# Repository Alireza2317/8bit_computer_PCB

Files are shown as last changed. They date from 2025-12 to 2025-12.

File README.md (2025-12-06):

# PCB Design of Ben Eater's 8-Bit Computer 🖥️





A complete **Printed Circuit Board (PCB)** implementation of the famous 8-bit computer architecture (SAP-1) designed by Ben Eater.

Moving from breadboards to a production-ready PCB, this project demonstrates complex signal routing, hierarchical schematic organization, and digital logic design using the **74xx TTL series** chips.

## 📸 3D Render
<p align="center">
  3D Top View
</p>

## ⚙️ Technical Specifications
| Feature | Details |
| :--- | :--- |
| **EDA Software** | KiCad |
| **Architecture** | Simple As Possible |
| **Logic Family** | 74LS / 74HC Series (TTL) |
| **PCB Layers** | 2 Layers |
| **Mounting** | Through-Hole Technology (THT) |

## 🧠 Design Challenges & Features
* **Hierarchical Schematics:** The design is broken down into modular logical blocks (Clock, RAM, ALU, Control Logic) using KiCad's hierarchical sheets for maintainability.
* **Complex Routing:** Managing hundreds of data and control lines on a 2-layer board required careful optimization of trace paths to minimize vias and ensure signal integrity.
* **Bus Architecture:** Implements a central 8-bit bus connecting all registers and the Arithmetic Logic Unit.

## 🖼️ Gallery

#### PCB Layout
<p align="center">
  PCB Layout
</p>

#### 3d View Snapshot
<p align="center">
  3D Top View
</p>

### Schematics (Sneak Peek)

#### Root schematic page
<p align="center">
  root schematics
</p>

#### RAM Module
<p align="center">
	Memory schematics
</p>

## 🚀 How to Open
1. **Clone the repository:**
   ```bash
   git clone https://github.com/Alireza2317/8bit_computer_PCB
   ```
2. **Open in KiCad:**
   * Launch **KiCad**.
   * Go to `File > Open Project`.
   * Select the `.kicad_pro` file in the root directory.
3. **Explore:**
   * Click the **Schematic Editor** to see the logic.
   * Click the **PCB Editor** to see the physical routing.

## 👏 Acknowledgments
This project is based on the incredible educational series by **Ben Eater**.
* [Ben Eater's Website](https://eater.net/8bit)
* [YouTube Playlist](https://www.youtube.com/playlist?list=PLowKtXNTBypGqImE405J2565dvjafglHU)

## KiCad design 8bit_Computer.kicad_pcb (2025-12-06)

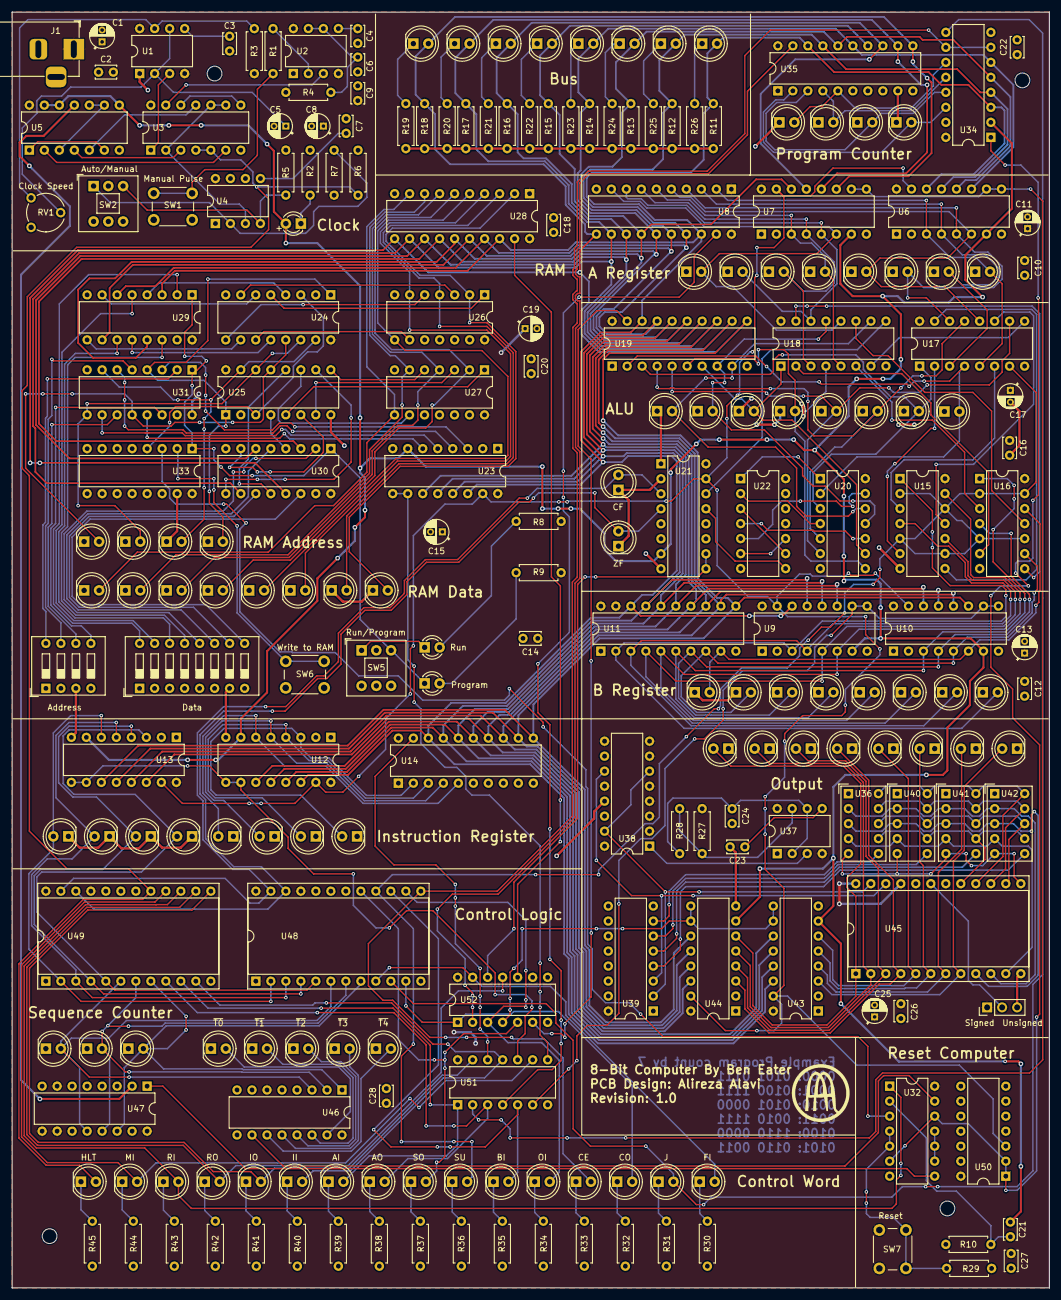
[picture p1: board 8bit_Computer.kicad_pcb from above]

Board: 2 copper layers, 175.6 x 216.0 mm, 232 parts (0 on the bottom side), 231 nets.

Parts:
C1, C5: 100nF; CP_Radial_D4.0mm_P2.00mm
C2, C9, C14, C16, C18, C21: 1uF; C_Disc_D3.4mm_W2.1mm_P2.50mm
C3, C4, C7, C10, C12, C20, C22, C23, C24, C26, C27, C28: 10nF; C_Disc_D3.4mm_W2.1mm_P2.50mm
C6: 100nF; C_Disc_D3.4mm_W2.1mm_P2.50mm
C8: 2.2uF; CP_Radial_D4.0mm_P2.00mm
C11, C15, C17, C19: 10nF; CP_Radial_D4.0mm_P2.00mm
C13, C25: 1uF; CP_Radial_D4.0mm_P2.00mm
D1: bus7; LED_D3.0mm
D2: bus6; LED_D5.0mm
D3: bus5; LED_D5.0mm
D4: bus4; LED_D5.0mm
D5: bus3; LED_D5.0mm
D6: bus2; LED_D5.0mm
D7: bus1; LED_D5.0mm
D8: bus0; LED_D5.0mm
D9: pc3; LED_D5.0mm
D10: pc2; LED_D5.0mm
D11: pc1; LED_D5.0mm
D12: pc0; LED_D5.0mm
D13: Clock LED; LED_D5.0mm
D14: a7; LED_D5.0mm
D15: a6; LED_D5.0mm
D16: a5; LED_D5.0mm
D17: a4; LED_D5.0mm
D18: a3; LED_D5.0mm
D19: a2; LED_D5.0mm
D20: a0; LED_D5.0mm
D21: a1; LED_D5.0mm
D22: s7; LED_D5.0mm
D23: s5; LED_D5.0mm
D24: s6; LED_D5.0mm
D25: s4; LED_D5.0mm
D26: s3; LED_D5.0mm
D27: s2; LED_D5.0mm
D28: s1; LED_D5.0mm
D29: s0; LED_D5.0mm
D30: CF; LED_D5.0mm
D31: ra3; LED_D5.0mm
D32: ra2; LED_D5.0mm
D33: ra0; LED_D5.0mm
D34: ra1; LED_D5.0mm
D35: ZF; LED_D5.0mm
D36: r7; LED_D5.0mm
D37: r6; LED_D5.0mm
D38: r4; LED_D5.0mm
D39: r5; LED_D5.0mm
D40: r3; LED_D5.0mm
D41: r2; LED_D5.0mm
D42: r0; LED_D5.0mm
D43: r1; LED_D5.0mm
D44: Run; LED_D5.0mm
D45: Program; LED_D5.0mm
D46: b6; LED_D5.0mm
D47: b7; LED_D5.0mm
D48: b5; LED_D3.0mm
D49: b4; LED_D3.0mm
D50: b2; LED_D5.0mm
D51: b3; LED_D5.0mm
D52: b0; LED_D5.0mm
D53: b1; LED_D5.0mm
D54: out7; LED_D5.0mm
D55: out6; LED_D5.0mm
D56: out5; LED_D5.0mm
D57: out3; LED_D5.0mm
D58: out4; LED_D5.0mm
D59: out2; LED_D5.0mm
D60: out1; LED_D5.0mm
D61: out0; LED_D5.0mm
D62: ir7; LED_D5.0mm
D63: ir6; LED_D5.0mm
D64: ir5; LED_D5.0mm
D65: ir3; LED_D5.0mm
D66: ir4; LED_D5.0mm
D67: ir2; LED_D5.0mm
D68: ir1; LED_D5.0mm
D69: ir0; LED_D5.0mm
D70: sc1; LED_D5.0mm
D71: sc2; LED_D5.0mm
D72: sc0; LED_D5.0mm
D73: T0; LED_D5.0mm
D74: T2; LED_D5.0mm
D75: T1; LED_D5.0mm
D76: T4; LED_D5.0mm
D77: T3; LED_D5.0mm
D78: HLT; LED_D5.0mm
D79: MAR_In; LED_D5.0mm
D80: RAM_In; LED_D5.0mm
D81: RAM_Out; LED_D5.0mm
D82: IR_Out; LED_D5.0mm
D83: IR_In; LED_D5.0mm
D84: A_Out; LED_D5.0mm
D85: A_In; LED_D5.0mm
D86: Sum_Out; LED_D5.0mm
D87: Subtract; LED_D5.0mm
D88: Out_In; LED_D5.0mm
D89: B_In; LED_D5.0mm
D90: PC_En; LED_D5.0mm
D91: PC_Out; LED_D5.0mm
D92: Jump; LED_D5.0mm
D93: Flags_In; LED_D5.0mm
J1: DC Input; BarrelJack_Horizontal
J2: Sign Mode Jumper; PinHeader_1x03_P2.54mm_Vertical
M1, M2, M3, M4: MountingHole_2.5mm
R1, R3, R20, R22, R27: 1K; R_Axial_DIN0207_L6.3mm_D2.5mm_P7.62mm_Horizontal
R2: 1M; R_Axial_DIN0207_L6.3mm_D2.5mm_P7.62mm_Horizontal
R4, R5, R7, R9, R11, R13, R16, R19: 100; R_Axial_DIN0207_L6.3mm_D2.5mm_P7.62mm_Horizontal
R6, R8, R10, R12, R14, R15, R17, R18, R23, R44: 10K; R_Axial_DIN0207_L6.3mm_D2.5mm_P7.62mm_Horizontal
R21, R24, R25, R28, R29, R30, R31, R32, R33, R34, R35, R36, R37, R38, R39, R40, R41, R42, R43: 330; R_Axial_DIN0207_L6.3mm_D2.5mm_P7.62mm_Horizontal
R26: 100K; R_Axial_DIN0207_L6.3mm_D2.5mm_P7.62mm_Horizontal
R45: 1k; R_Axial_DIN0207_L6.3mm_D2.5mm_P7.62mm_Horizontal
RV1: 100K; Potentiometer_Piher_PT-6-V_Vertical
SW1: Clock Mode Switch; SW_PUSH_6mm
SW2: Manual Pulse; SW_Push_2P2T_Toggle_CK_PVA2OAH5xxxxxxV2
SW3: Program Address; SW_DIP_SPSTx04_Slide_9.78x12.34mm_W7.62mm_P2.54mm
SW4: Program Data; SW_DIP_SPSTx08_Slide_9.78x22.5mm_W7.62mm_P2.54mm
SW5: Program Button; SW_Push_2P2T_Toggle_CK_PVA2OAH5xxxxxxV2
SW6: Program/Run Mode Switch; SW_PUSH_6mm
SW7: Reset Button; SW_PUSH_6mm
U1, U2: NE555P; DIP-8_W7.62mm
U3: 74LS245; DIP-14_W7.62mm
U4: 74LS00; DIP-8_W7.62mm
U5, U50, U52: 74LS00; DIP-14_W7.62mm
U6, U9, U18, U29, U34: 74LS245; DIP-16_W7.62mm
U7, U47: 74LS161; DIP-16_W7.62mm
U8: NE555P; DIP-20_W7.62mm
U10, U23, U24, U30, U31, U33, U44: 74LS173; DIP-16_W7.62mm
U11: 74LS173; DIP-20_W7.62mm
U12, U21: 74LS157; DIP-16_W7.62mm
U13: 74LS189; DIP-16_W7.62mm
U14: 74LS04; DIP-20_W7.62mm
U15: 74LS189; DIP-14_W7.62mm
U16, U22: 74LS157; DIP-14_W7.62mm
U17: 74LS04; DIP-16_W7.62mm
U19: 74LS283; DIP-20_W7.62mm
U20: 74LS283; DIP-14_W7.62mm
U25: 74LS08; DIP-16_W7.62mm
U26: 74LS02; DIP-14_W7.62mm
U27: 74LS86; DIP-14_W7.62mm
U28: 74LS86; DIP-20_W7.62mm
U32: 74LS173; DIP-14_W7.62mm
U35: 74LS76; DIP-20_W7.62mm
U36: NE555D; HDSP-7401
U37: Hundred's Place; DIP-8_W7.62mm
U38: Minus Sign; DIP-16_W7.62mm
U39: Ten's Place; DIP-16_W7.62mm
U40: One's Place; HDSP-7401
U41, U42: 28c16; HDSP-7401
U43: 74LS139; DIP-16_W7.62mm
U45: 74LS173; DIP-24_W15.24mm_Socket
U46: 28c16; DIP-16_W7.62mm
U48: 74LS138; DIP-24_W15.24mm_Socket
U49: 74LS06; DIP-24_W15.24mm_Socket
U51: 74LS06; DIP-14_W7.62mm

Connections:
/A Register/a0: D9.2 (A), U6.3 (Q0), U8.2 (A0), U17.5 (A1)
/A Register/a1: D8.2 (A), U6.4 (Q1), U8.3 (A1), U17.3 (A2)
/A Register/a2: D7.2 (A), U6.5 (Q2), U8.4 (A2), U17.14 (A3)
/A Register/a3: D6.2 (A), U6.6 (Q3), U8.5 (A3), U17.12 (A4)
/A Register/a4: D5.2 (A), U7.3 (Q0), U8.6 (A4), U18.5 (A1)
/A Register/a5: D4.2 (A), U7.4 (Q1), U8.7 (A5), U18.3 (A2)
/A Register/a6: D3.2 (A), U7.5 (Q2), U8.8 (A6), U18.14 (A3)
/A Register/a7: D2.2 (A), U7.6 (Q3), U8.9 (A7), U18.12 (A4)
/ALU/Flags Register/zero_bit: U21.13 (D1), U22.8
/ALU/bc0: U15.3, U17.6 (B1)
/ALU/bc1: U15.6, U17.2 (B2)
/ALU/bc2: U15.8, U17.15 (B3)
/ALU/bc3: U15.11, U17.11 (B4)
/ALU/bc4: U16.3, U18.6 (B1)
/ALU/bc5: U16.6, U18.2 (B2)
/ALU/bc6: U16.8, U18.15 (B3)
/ALU/bc7: U16.11, U18.11 (B4)
/ALU/carry_bit: U18.9 (C4), U21.14 (D0)
/ALU/middle_carry: U17.9 (C4), U18.7 (C0)
/ALU/s0: D33.2 (A), U17.4 (S1), U19.2 (A0), U20.2
/ALU/s1: D32.2 (A), U17.1 (S2), U19.3 (A1), U20.3
/ALU/s2: D31.2 (A), U17.13 (S3), U19.4 (A2), U20.5
/ALU/s3: D30.2 (A), U17.10 (S4), U19.5 (A3), U20.6
/ALU/s4: D29.2 (A), U18.4 (S1), U19.6 (A4), U20.8
/ALU/s5: D28.2 (A), U18.1 (S2), U19.7 (A5), U20.9
/ALU/s6: D27.2 (A), U18.13 (S3), U19.8 (A6), U20.11
/ALU/s7: D26.2 (A), U18.10 (S4), U19.9 (A7), U20.12
/B Register/b0: D17.2 (A), U9.3 (Q0), U11.2 (A0), U15.1
/B Register/b1: D16.2 (A), U9.4 (Q1), U11.3 (A1), U15.4
/B Register/b2: D15.2 (A), U9.5 (Q2), U11.4 (A2), U15.10
/B Register/b3: D14.2 (A), U9.6 (Q3), U11.5 (A3), U15.13
/B Register/b4: D13.2 (A), U10.3 (Q0), U11.6 (A4), U16.1
/B Register/b5: D12.2 (A), U10.4 (Q1), U11.7 (A5), U16.4
/B Register/b6: D11.2 (A), U10.5 (Q2), U11.8 (A6), U16.9
/B Register/b7: D10.2 (A), U10.6 (Q3), U11.9 (A7), U16.12
/Clock Module/AO: U1.3 (Q), U3.1
/Clock Module/MO: U2.3 (Q), U3.13
/Clock Module/select clock mode: U3.2, U3.9, U3.10, U4.3 (Q)
/Control Logic/sc0: D75.2 (A), U46.1 (A0), U47.14 (Q0), U48.8 (A0), U49.8 (A0)
/Control Logic/sc1: D73.2 (A), U46.2 (A1), U47.13 (Q1), U48.7 (A1), U49.7 (A1)
/Control Logic/sc2: D71.2 (A), U46.3 (A2), U47.12 (Q2), U48.6 (A2), U49.6 (A2)
/Control Logic/~T0: D70.2 (A), U46.15 (O0)
/Control Logic/~T1: D72.2 (A), U46.14 (O1)
/Control Logic/~T2: D74.2 (A), U46.13 (O2)
/Control Logic/~T3: D76.2 (A), U46.12 (O3)
/Control Logic/~T4: D77.2 (A), U46.11 (O4)
/Control Logic/~T5: U32.13, U46.10 (O5)
/Control Logic/~sq_mr: U32.8, U47.1 (~MR)
/Display/a: U36.10 (A), U40.10 (A), U41.10 (A), U42.10 (A), U45.16 (I/O6)
/Display/b: U36.9 (B), U40.9 (B), U41.9 (B), U42.9 (B), U45.15 (I/O5)
/Display/c: U36.8 (C), U40.8 (C), U41.8 (C), U42.8 (C), U45.14 (I/O4)
/Display/d: U36.5 (D), U40.5 (D), U41.5 (D), U42.5 (D), U45.13 (I/O3)
/Display/dp: U36.7 (DP), U40.7 (DP), U41.7 (DP), U42.7 (DP), U45.17 (I/O7)
/Display/e: U36.4 (E), U40.4 (E), U41.4 (E), U42.4 (E), U45.11 (I/O2)
/Display/f: U36.2 (F), U40.2 (F), U41.2 (F), U42.2 (F), U45.10 (I/O1)
/Display/g: U36.3 (G), U40.3 (G), U41.3 (G), U42.3 (G), U45.9 (I/O0)
/Display/hundreds: U39.6 (O2), U40.6 (CC)
/Display/mc0: U38.6 (C), U38.15 (Q), U39.2 (A0), U45.23 (A8)
/Display/mc1: U38.11 (Q), U39.3 (A1), U45.22 (A9)
/Display/mux_clock: U37.3 (Q), U38.1 (C)
/Display/ones: U39.4 (O0), U42.6 (CC)
/Display/out0: D69.2 (A), U43.3 (Q0), U45.8 (A0)
/Display/out1: D68.2 (A), U43.4 (Q1), U45.7 (A1)
/Display/out2: D67.2 (A), U43.5 (Q2), U45.6 (A2)
/Display/out3: D66.2 (A), U43.6 (Q3), U45.5 (A3)
/Display/out4: D65.2 (A), U44.3 (Q0), U45.4 (A4)
/Display/out5: D64.2 (A), U44.4 (Q1), U45.3 (A5)
/Display/out6: D63.2 (A), U44.5 (Q2), U45.2 (A6)
/Display/out7: D62.2 (A), U44.6 (Q3), U45.1 (A7)
/Display/sign: U36.6 (CC), U39.7 (O3)
/Display/tens: U39.5 (O1), U41.6 (CC)
/Instruction Register/ir0: D25.2 (A), U12.3 (Q0), U14.2 (A0)
/Instruction Register/ir1: D24.2 (A), U12.4 (Q1), U14.3 (A1)
/Instruction Register/ir2: D23.2 (A), U12.5 (Q2), U14.4 (A2)
/Instruction Register/ir3: D22.2 (A), U12.6 (Q3), U14.5 (A3)
/Instruction Register/ir4: D21.2 (A), U13.3 (Q0), U48.5 (A3), U49.5 (A3)
/Instruction Register/ir5: D20.2 (A), U13.4 (Q1), U48.4 (A4), U49.4 (A4)
/Instruction Register/ir6: D19.2 (A), U13.5 (Q2), U48.3 (A5), U49.3 (A5)
/Instruction Register/ir7: D18.2 (A), U13.6 (Q3), U48.2 (A6), U49.2 (A6)
/Program Counter/pc0: D53.2 (A), U34.14 (Q0), U35.2 (A0)
/Program Counter/pc1: D52.2 (A), U34.13 (Q1), U35.3 (A1)
/Program Counter/pc2: D51.2 (A), U34.12 (Q2), U35.4 (A2)
/Program Counter/pc3: D50.2 (A), U34.11 (Q3), U35.5 (A3)
/RAM/Computer Mode Switcher/di0: U24.4 (D1), U29.4 (Za)
/RAM/Computer Mode Switcher/di1: U24.6 (D2), U29.7 (Zb)
/RAM/Computer Mode Switcher/di2: U24.10 (D3), U29.9 (Zc)
/RAM/Computer Mode Switcher/di3: U24.12 (D4), U29.12 (Zd)
/RAM/Computer Mode Switcher/di4: U25.4 (D1), U30.4 (Za)
/RAM/Computer Mode Switcher/di5: U25.6 (D2), U30.7 (Zb)
/RAM/Computer Mode Switcher/di6: U25.10 (D3), U30.9 (Zc)
/RAM/Computer Mode Switcher/di7: U25.12 (D4), U30.12 (Zd)
/RAM/Computer Mode Switcher/mar0: U23.3 (Q0), U31.3 (I1a)
/RAM/Computer Mode Switcher/mar1: U23.4 (Q1), U31.6 (I1b)
/RAM/Computer Mode Switcher/mar2: U23.5 (Q2), U31.10 (I1c)
/RAM/Computer Mode Switcher/mar3: U23.6 (Q3), U31.13 (I1d)
/RAM/Computer Mode Switcher/pa0: SW3.8, U31.2 (I0a)
/RAM/Computer Mode Switcher/pa1: SW3.7, U31.5 (I0b)
/RAM/Computer Mode Switcher/pa2: SW3.6, U31.11 (I0c)
/RAM/Computer Mode Switcher/pa3: SW3.5, U31.14 (I0d)
/RAM/Computer Mode Switcher/pd0: SW4.16, U29.2 (I0a)
/RAM/Computer Mode Switcher/pd1: SW4.15, U29.5 (I0b)
/RAM/Computer Mode Switcher/pd2: SW4.14, U29.11 (I0c)
/RAM/Computer Mode Switcher/pd3: SW4.13, U29.14 (I0d)
/RAM/Computer Mode Switcher/pd4: SW4.12, U30.2 (I0a)
/RAM/Computer Mode Switcher/pd5: SW4.11, U30.5 (I0b)
/RAM/Computer Mode Switcher/pd6: SW4.10, U30.11 (I0c)
/RAM/Computer Mode Switcher/pd7: SW4.9, U30.14 (I0d)
/RAM/Computer Mode Switcher/select r/p: D49.1 (K), SW5.3 (C), U29.1 (S), U30.1 (S), U31.1 (S), U33.1 (S)
/RAM/Computer Mode Switcher/~RAM_WE: U24.3 (~WE), U25.3 (~WE), U33.4 (Za)
/RAM/a0: D39.2 (A), U24.1 (A0), U25.1 (A0), U31.4 (Za)
/RAM/a1: D38.2 (A), U24.15 (A1), U25.15 (A1), U31.7 (Zb)
/RAM/a2: D37.2 (A), U24.14 (A2), U25.14 (A2), U31.9 (Zc)
/RAM/a3: D36.2 (A), U24.13 (A3), U25.13 (A3), U31.12 (Zd)
/RAM/r0: D47.2 (A), U26.2, U28.2 (A0)
/RAM/r1: D46.2 (A), U26.4, U28.3 (A1)
/RAM/r2: D45.2 (A), U26.6, U28.4 (A2)
/RAM/r3: D44.2 (A), U26.8, U28.5 (A3)
/RAM/r4: D43.2 (A), U27.2, U28.6 (A4)
/RAM/r5: D42.2 (A), U27.4, U28.7 (A5)
/RAM/r6: D41.2 (A), U27.6, U28.8 (A6)
/RAM/r7: D40.2 (A), U27.8, U28.9 (A7)
A_In: D87.2 (A), U49.10 (I/O1), U51.1
A_Out: D86.2 (A), U49.9 (I/O0), U51.3
B_In: D83.2 (A), U48.15 (I/O5), U51.5
Bus0: D61.2 (A), R11.1, U6.14 (D0), U8.18 (B0), U9.14 (D0), U11.18 (B0), U12.14 (D0), U14.18 (B0), U19.18 (B0), U23.14 (D0), U28.18 (B0), U29.3 (I1a), U34.3 (D0), U35.18 (B0), U43.14 (D0)
Bus1: D60.2 (A), R12.1, U6.13 (D1), U8.17 (B1), U9.13 (D1), U11.17 (B1), U12.13 (D1), U14.17 (B1), U19.17 (B1), U23.13 (D1), U28.17 (B1), U29.6 (I1b), U34.4 (D1), U35.17 (B1), U43.13 (D1)
Bus2: D59.2 (A), R13.1, U6.12 (D2), U8.16 (B2), U9.12 (D2), U11.16 (B2), U12.12 (D2), U14.16 (B2), U19.16 (B2), U23.12 (D2), U28.16 (B2), U29.10 (I1c), U34.5 (D2), U35.16 (B2), U43.12 (D2)
Bus3: D58.2 (A), R14.1, U6.11 (D3), U8.15 (B3), U9.11 (D3), U11.15 (B3), U12.11 (D3), U14.15 (B3), U19.15 (B3), U23.11 (D3), U28.15 (B3), U29.13 (I1d), U34.6 (D3), U35.15 (B3), U43.11 (D3)
Bus4: D57.2 (A), R15.1, U7.14 (D0), U8.14 (B4), U10.14 (D0), U11.14 (B4), U13.14 (D0), U14.14 (B4), U19.14 (B4), U28.14 (B4), U30.3 (I1a), U35.14 (B4), U44.14 (D0)
Bus5: D56.2 (A), R16.1, U7.13 (D1), U8.13 (B5), U10.13 (D1), U11.13 (B5), U13.13 (D1), U14.13 (B5), U19.13 (B5), U28.13 (B5), U30.6 (I1b), U35.13 (B5), U44.13 (D1)
Bus6: D55.2 (A), R17.1, U7.12 (D2), U8.12 (B6), U10.12 (D2), U11.12 (B6), U13.12 (D2), U14.12 (B6), U19.12 (B6), U28.12 (B6), U30.10 (I1c), U35.12 (B6), U44.12 (D2)
Bus7: D54.2 (A), R18.1, U7.11 (D3), U8.11 (B7), U10.11 (D3), U11.11 (B7), U13.11 (D3), U14.11 (B7), U19.11 (B7), U28.11 (B7), U30.13 (I1d), U35.11 (B7), U44.11 (D3)
CF: D35.2 (A), U21.3 (Q0), U48.23 (A8), U49.23 (A8)
Clock: C21.1, D1.2 (A), U5.8, U5.12, U5.13, U6.7 (Cp), U7.7 (Cp), U9.7 (Cp), U10.7 (Cp), U12.7 (Cp), U13.7 (Cp), U21.7 (Cp), U23.7 (Cp), U34.2 (CP), U43.7 (Cp), U44.7 (Cp)
Flags_In: D78.2 (A), U48.9 (I/O0), U52.13
GND: C1.2, C2.1, C3.1, C4.1, C5.2, C6.1, C7.1, C8.2, C9.1, C10.2, C11.2, C12.2, C13.2, C14.2, C15.2, C16.2, C17.2, C18.2, C19.2, C20.2, C22.2, C23.2, C24.2, C25.2, C26.2, C27.2, C28.2, D2.1 (K), D3.1 (K), D4.1 (K), D5.1 (K), D6.1 (K), D7.1 (K), D8.1 (K), D9.1 (K), D10.1 (K), D11.1 (K), D12.1 (K), D13.1 (K), D14.1 (K), D15.1 (K), D16.1 (K), D17.1 (K), D18.1 (K), D19.1 (K), D20.1 (K), D21.1 (K), D22.1 (K), D23.1 (K), D24.1 (K), D25.1 (K), D26.1 (K), D27.1 (K), D28.1 (K), D29.1 (K), D30.1 (K), D31.1 (K), D32.1 (K), D33.1 (K), D34.1 (K), D35.1 (K), D36.1 (K), D37.1 (K), D38.1 (K), D39.1 (K), D40.1 (K), D41.1 (K), D42.1 (K), D43.1 (K), D44.1 (K), D45.1 (K), D46.1 (K), D47.1 (K), D50.1 (K), D51.1 (K), D52.1 (K), D53.1 (K), D62.1 (K), D63.1 (K), D64.1 (K), D65.1 (K), D66.1 (K), D67.1 (K), D68.1 (K), D69.1 (K), D70.1 (K), D71.1 (K), D72.1 (K), D73.1 (K), D74.1 (K), D75.1 (K), D76.1 (K), D77.1 (K), J1.2, J2.3, R2.2, R6.2, R10.2, R11.2, R12.2, R13.2, R14.2, R15.2, R16.2, R17.2, R18.2, R19.2, R20.2, R21.2, R22.2, R23.2, R24.2, R25.2, R26.2, R29.2, R30.2, R31.2, R32.2, R33.2, R34.2, R35.2, R36.2, R37.2, R38.2, R39.2, R40.2, R41.2, R42.2, R43.2, R44.2, R45.2, SW1.1, SW2.2 (B), SW3.1, SW3.2, SW3.3, SW3.4, SW4.1, SW4.2, SW4.3, SW4.4, SW4.5, SW4.6, SW4.7, SW4.8, SW5.2 (B), SW6.1, U1.1 (GND), U2.1 (GND), U3.7 (GND), U4.1 (GND), U4.6 (THR), U5.7 (GND), U6.1 (Oe1), U6.2 (Oe2), U6.8 (GND), U7.1 (Oe1), U7.2 (Oe2), U7.8 (GND), U8.10 (GND), U9.1 (Oe1), U9.2 (Oe2), U9.8 (GND), U10.1 (Oe1), U10.2 (Oe2), U10.8 (GND), U11.10 (GND), U12.1 (Oe1), U12.2 (Oe2), U12.8 (GND), U13.1 (Oe1), U13.2 (Oe2), U13.8 (GND), U14.6 (A4), U14.7 (A5), U14.8 (A6), U14.9 (A7), U14.10 (GND), U15.7 (GND), U16.7 (GND), U17.8 (GND), U18.8 (GND), U19.10 (GND), U20.7 (GND), U21.1 (Oe1), U21.2 (Oe2), U21.8 (GND), U22.7 (GND), U23.1 (Oe1), U23.2 (Oe2), U23.8 (GND), U24.2 (~CS), U24.8 (GND), U25.2 (~CS), U25.8 (GND), U26.7 (GND), U27.7 (GND), U28.10 (GND), U29.8 (GND), U29.15 (E), U30.8 (GND), U30.15 (E), U31.8 (GND), U31.15 (E), U32.7 (GND), U33.8 (GND), U33.15 (E), U34.8 (GND), U35.6 (A4), U35.7 (A5), U35.8 (A6), U35.9 (A7), U35.10 (GND), U37.1 (GND), U38.13 (GND), U39.1 (E), U39.8 (GND), U43.1 (Oe1), U43.2 (Oe2), U43.8 (GND), U44.1 (Oe1), U44.2 (Oe2), U44.8 (GND), U45.12 (GND), U45.18 (~CE), U45.20 (~OE), U46.4 (E1), U46.5 (E2), U46.8 (GND), U47.8 (GND), U48.12 (GND), U48.18 (~CE), U48.19 (A10), U48.20 (~OE), U49.1 (A7), U49.12 (GND), U49.18 (~CE), U49.19 (A10), U49.20 (~OE), U50.7 (GND), U51.7 (GND), U52.7 (GND)
HLT: D93.2 (A), R6.1, U3.4, U3.5, U49.17 (I/O7)
IR_In: D88.2 (A), U49.11 (I/O2), U51.11
IR_Out: D89.2 (A), U49.13 (I/O3), U51.13
Inverted Clock: U5.11, U47.2 (CP)
Jump: D79.2 (A), U34.9 (~PE), U48.10 (I/O1)
MAR_In: D92.2 (A), U49.16 (I/O6), U51.9
unnamed: C21.2, R10.1, U32.2
unnamed: D1.1 (K), R2.1
unnamed: D48.2 (A), R8.2
unnamed: D48.1 (K), SW5.1 (A)
unnamed: D49.2 (A), R9.2
unnamed: D54.1 (K), R19.1
unnamed: D55.1 (K), R20.1
unnamed: D56.1 (K), R21.1
unnamed: D57.1 (K), R22.1
unnamed: D58.1 (K), R23.1
unnamed: D59.1 (K), R24.1
unnamed: D60.1 (K), R25.1
unnamed: D61.1 (K), R26.1
unnamed: D78.1 (K), R30.1
unnamed: D79.1 (K), R31.1
unnamed: D80.1 (K), R32.1
unnamed: D81.1 (K), R33.1
unnamed: D82.1 (K), R34.1
unnamed: D83.1 (K), R35.1
unnamed: D84.1 (K), R36.1
unnamed: D85.1 (K), R37.1
unnamed: D86.1 (K), R38.1
unnamed: D87.1 (K), R39.1
unnamed: D88.1 (K), R40.1
unnamed: D89.1 (K), R41.1
unnamed: D90.1 (K), R42.1
unnamed: D91.1 (K), R43.1
unnamed: D92.1 (K), R44.1
unnamed: D93.1 (K), R45.1
unnamed: R1.2, SW1.2
unnamed: R29.1, SW7.2, U32.4, U32.5
unnamed: C3.2, U1.5 (CV)
unnamed: R3.2, RV1.3, U1.7 (DIS)
unnamed: C5.1, RV1.2, U1.2 (TR), U1.6 (THR)
unnamed: C4.2, U2.5 (CV)
unnamed: C6.2, R4.2, U2.6 (THR), U2.7 (DIS)
unnamed: R1.1, U2.2 (TR)
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

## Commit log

2025-01-27 added all the project files
    also added the gerber zip file
    [8bit_Computer.kicad_sch, ALU.kicad_sch, A_Register.kicad_sch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]
2025-12-06 updated kicad version from 7 to 9!
    [8bit_Computer.kicad_pcb, 8bit_Computer.kicad_sch, ALU.kicad_sch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]

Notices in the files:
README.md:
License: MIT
